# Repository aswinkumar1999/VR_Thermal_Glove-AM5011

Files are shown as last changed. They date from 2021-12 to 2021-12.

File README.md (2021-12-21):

# Virtual reality glove with Thermal Feedback - AM5011

Course Project for AM5011

**Abstract** :  The goal of the is to prototype an affordable VR gloves with thermal interface that provides thermal sensation when the user interacts with the virtual world.

**[Video](https://www.youtube.com/watch?v=WOqCuXHhvuI)** : https://www.youtube.com/watch?v=WOqCuXHhvuI   ( __Subtitles available for Non-Tamil viewers.__)

Unity Package for Oculus Quest 2 : https://drive.google.com/file/d/1xBs8NeNjcjLqpN7lWxxVzRwR7QExw7Z_/view?usp=sharing

Kindly note , this APK will only work on Quest and Quest 2 and requires Hand tracking access! This Unity package is incomplete, meaning you can use whichever method of communication you prefer with the hardware you make. 

The application was run on [Oculus Quest 2](https://www.oculus.com/)

Final prototype : 

<p float="left">
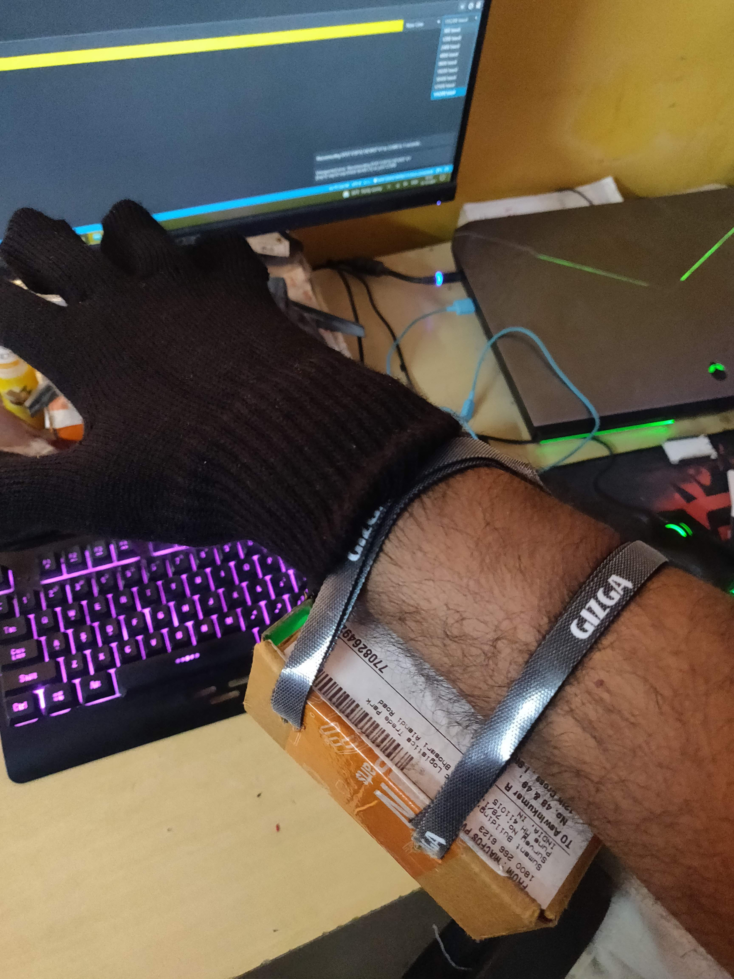
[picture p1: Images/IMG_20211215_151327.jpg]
  
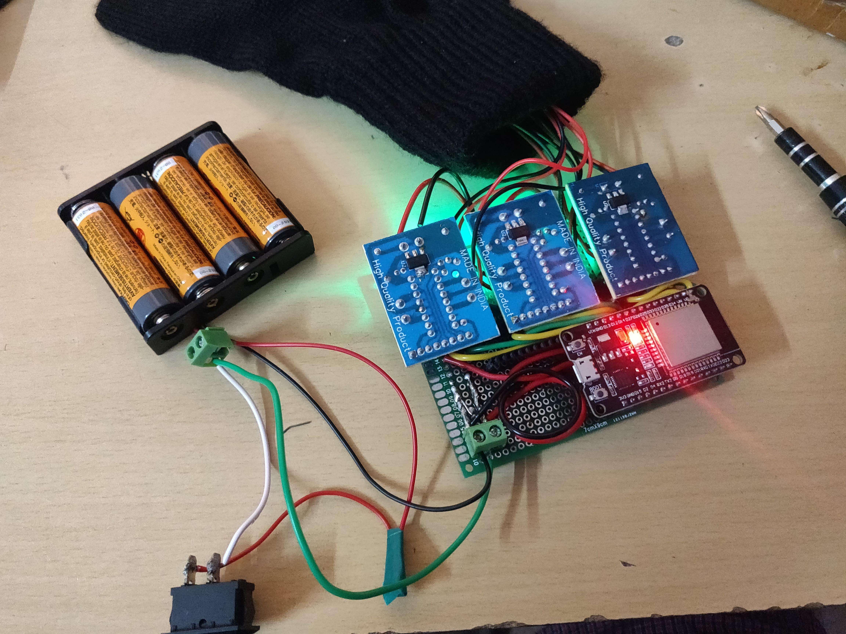
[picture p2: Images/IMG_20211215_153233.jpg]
   
</p>

Schematic : Fritzing file included for designing PCBs for the same.

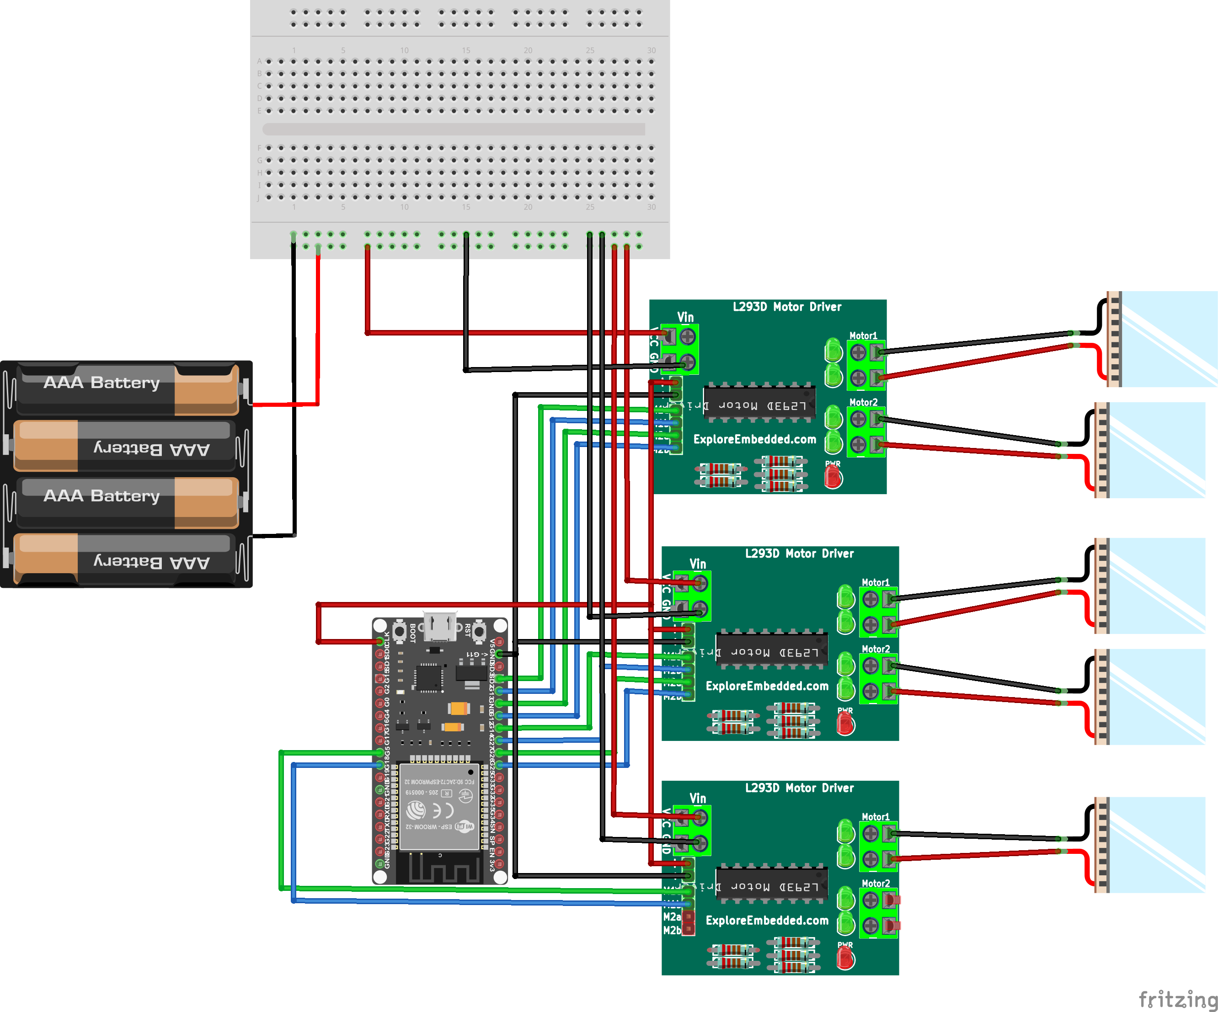
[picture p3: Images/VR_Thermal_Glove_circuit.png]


Code : [ESP32_Glove.ino](https://github.com/aswinkumar1999/VR_Thermal_Glove-AM5011/blob/main/ESP_32_Glove.ino)

----

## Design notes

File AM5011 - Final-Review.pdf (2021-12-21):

# AM5011 - Course Project

# VR Gloves with Thermal Interface

Aswinkumar - EP18B014

# Abstract

- The goal of the is to prototype an affordable VR gloves with thermal interface that provides thermal sensation when the user interacts with the virtual world.

# System block diagram

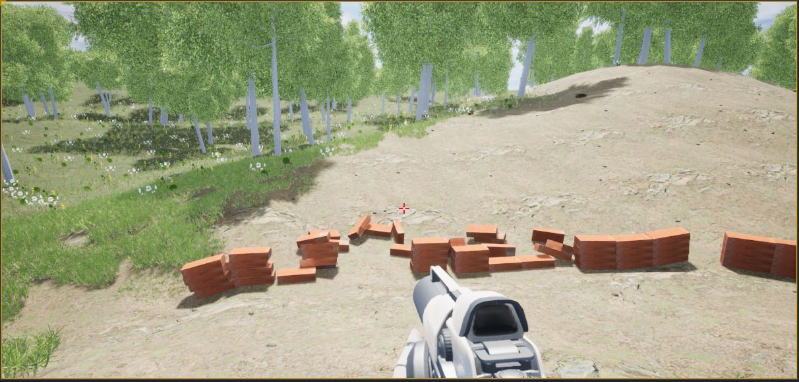
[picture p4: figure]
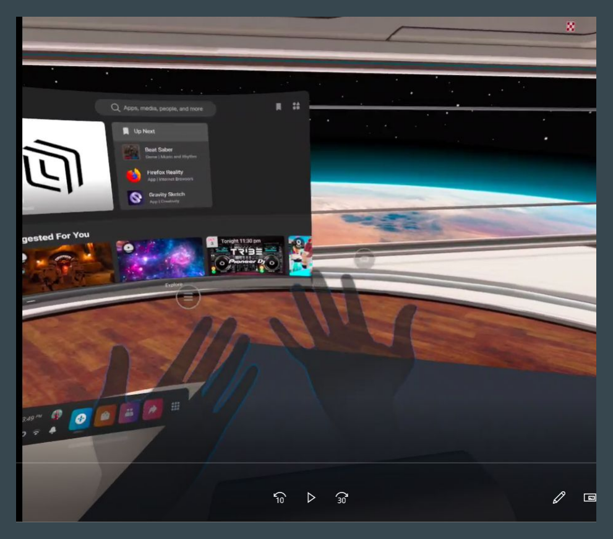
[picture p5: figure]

Need to finalise | Tested & works

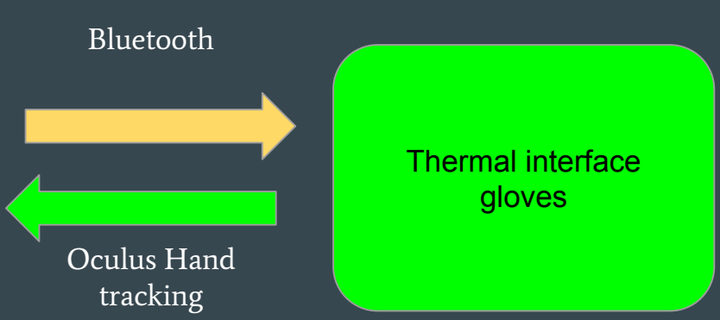
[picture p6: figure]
Thermal interface gloves; Oculus Hand tracking; Bluetooth

Unity

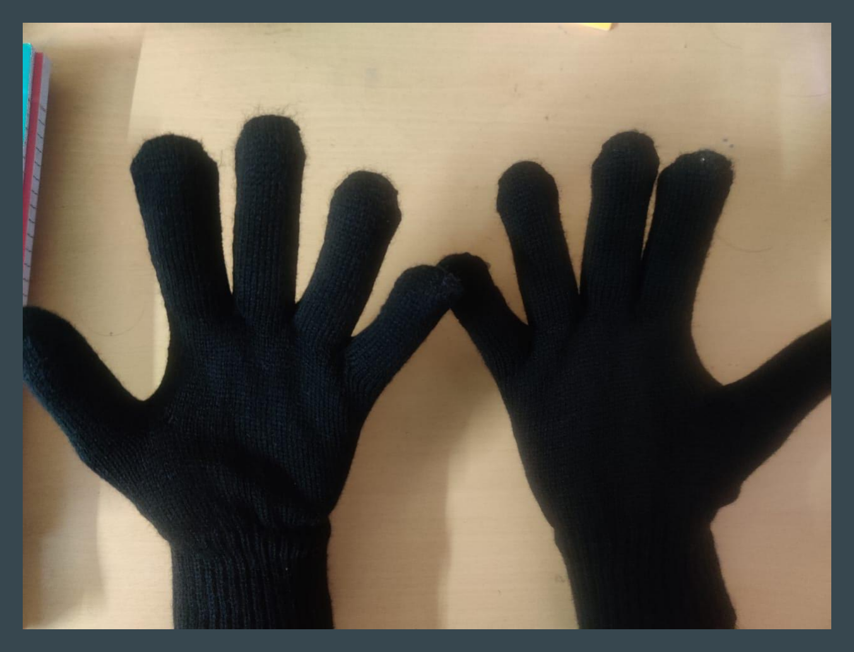
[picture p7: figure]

# Hardware setup

Bluetooth

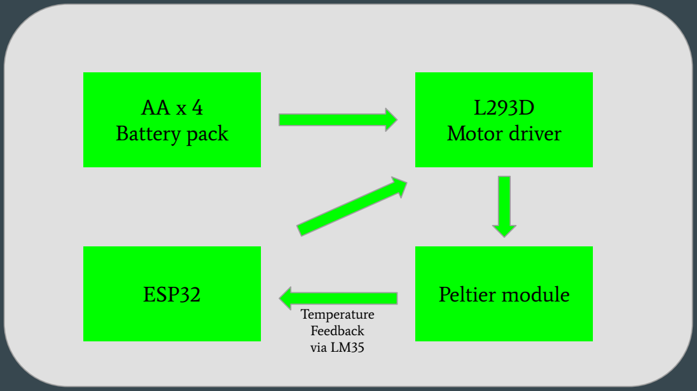
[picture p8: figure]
ESP32; Peltier module; L293D Motor driver; AA x 4 Battery pack; Temperature Feedback via LM35
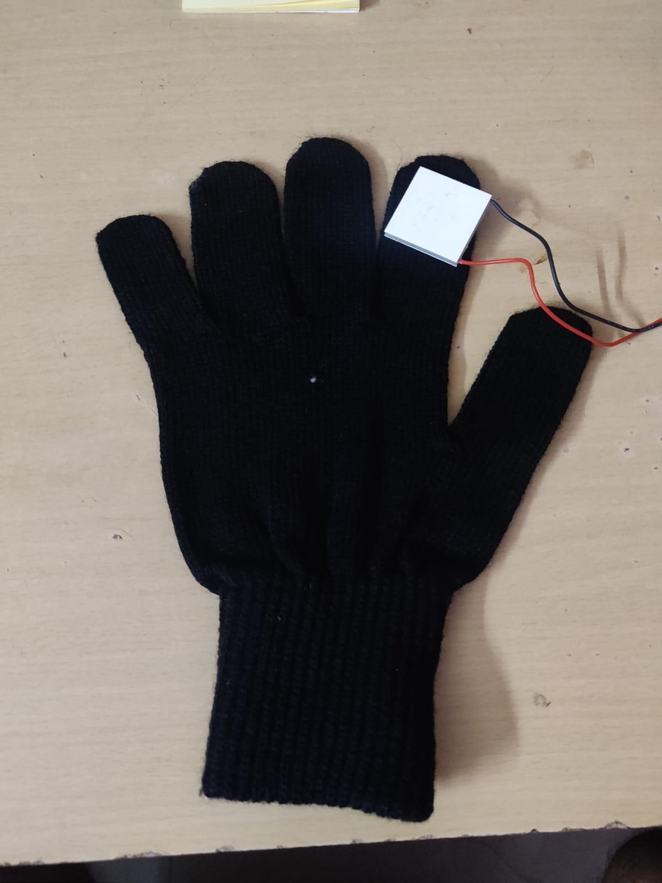
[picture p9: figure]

Need to finalise | Tested & works

# Results :

- Hardware for the project is complete , it is portable and works wirelessly with the battery pack.
- It is currently controlled using a Bluetooth application from an Android device.

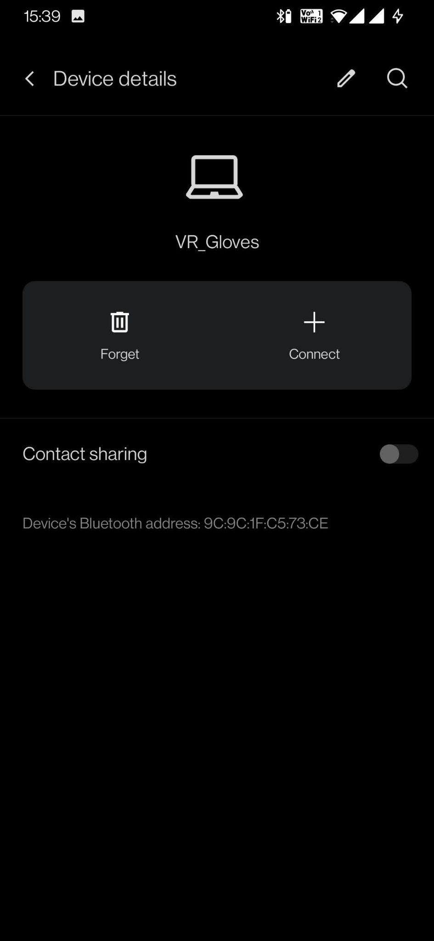
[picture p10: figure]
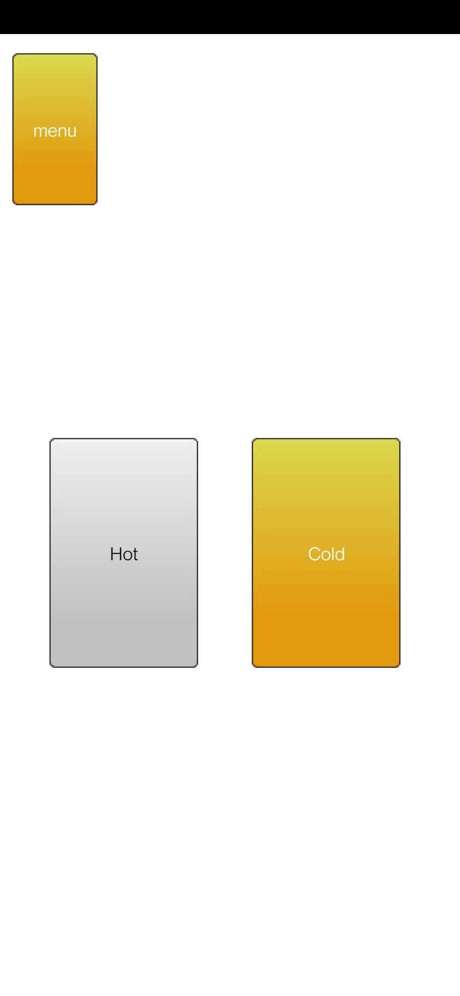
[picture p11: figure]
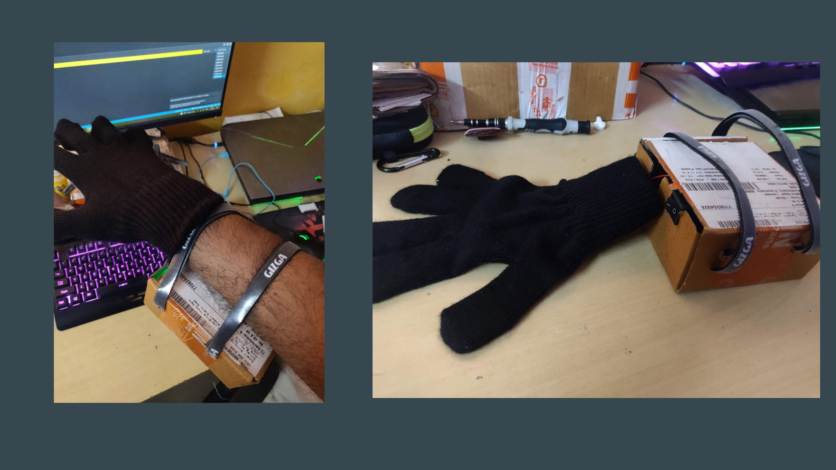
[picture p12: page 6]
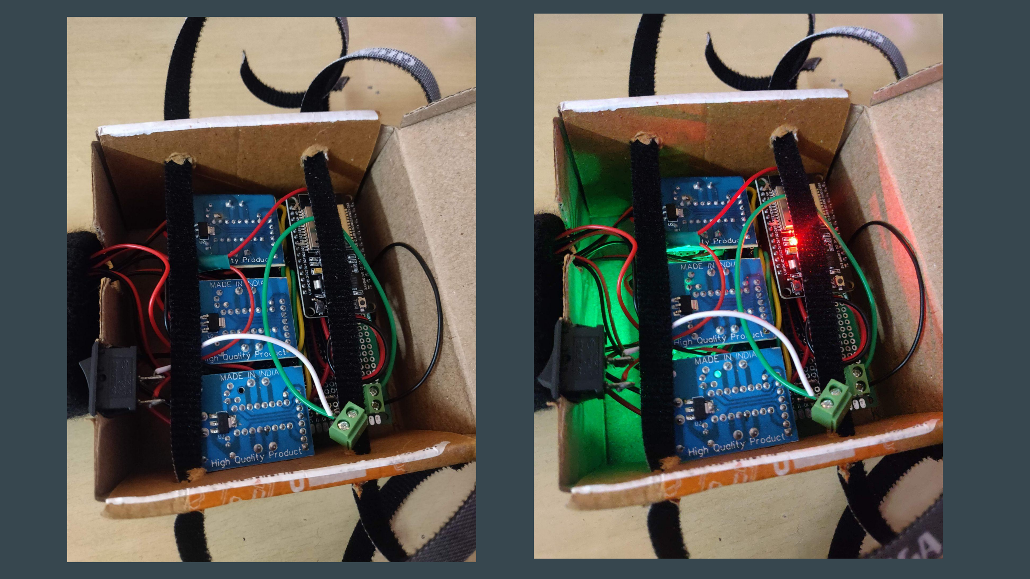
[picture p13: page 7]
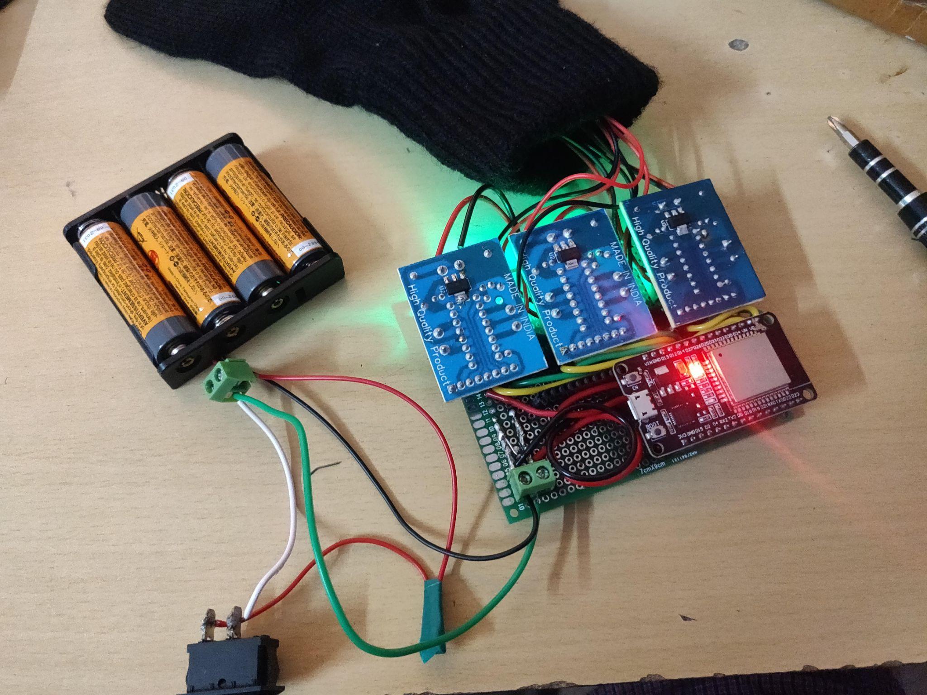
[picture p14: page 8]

# Issues faced while implementation :

- 6V battery packs in parallel crashes the SoC and a single pack has lower slope in change of temperature , need to switch to LiPo battery (7.4V)
- Oculus SDK Plugin Bluetooth issue , Bluetooth isn’t included in the Android manifest and is getting removed automatically.

# Plans for future :

- Changing battery pack to LiPo pack.
- Fixing the Unity bluetooth issue with Oculus plugin.
- Design and fabricate a PCB to have reduced footprint.
- Use a small 3d printed box to fit all the components.

# Something that I found very fascinating during the testing :

- I was pressing buttons for Hot/Cold testing and during the hot mode I involuntarily moved my hand towards my face and neck to transfer the hotness of my hand to my face only to realise that i had the system on ,

# Thank you

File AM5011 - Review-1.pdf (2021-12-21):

# AM5011 - Course Project

# VR Gloves with Interface

Review 1
Aswinkumar - EP18B014

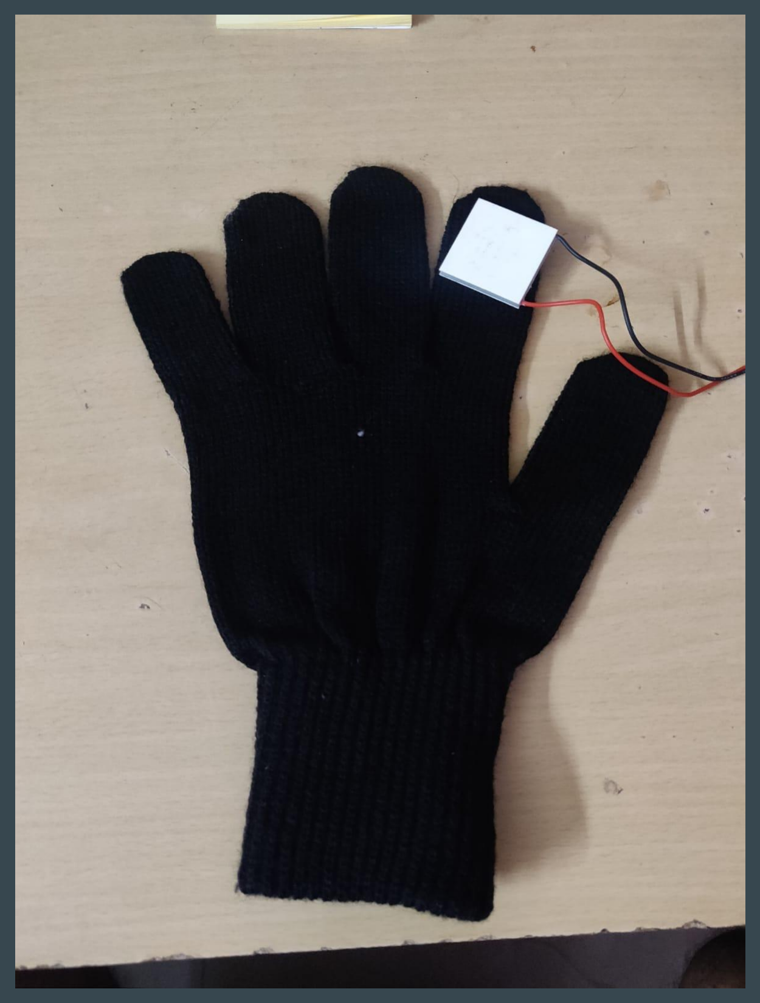
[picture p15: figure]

# VR Gloves with Thermal Interface

- The goal is the make an affordable VR gloves with thermal interface that provides thermal sensation when the user interacts with the virtual world.
- I will be only focusing on providing the sensation to the finger pad as they are one of the most sensitive part of our body.
- Ruffini cells and Nerve endings detect warmth
- Krause end bulb detect cold

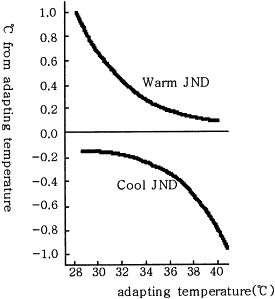
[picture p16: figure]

[1] Development of a temperature control procedure for a room air-conditioner using the concept of just noticeable difference (JND) in thermal sensation
[2] Thermal display glove for interacting with virtual reality

# System block diagram


Need to finalise | Tested & works

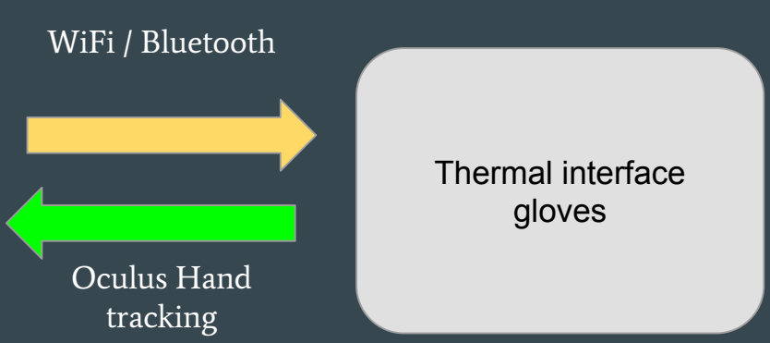
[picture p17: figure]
Thermal interface gloves; Oculus Hand tracking; WiFi / Bluetooth

Unity / Unreal


# Oculus hand-tracking :

The OVR Skeleton and OVR Hand APIs provide information required to render a fully articulated representation of the user’s real-life hands in VR without the use of controllers, including:

- Bone information
- Hand and finger position and orientation
- Pinch strength
- Pointer pose for UI raycasts
- Tracking confidence
- Hand size
- System gesture for opening the universal menu

# Hardware setup

WiFi / Bluetooth

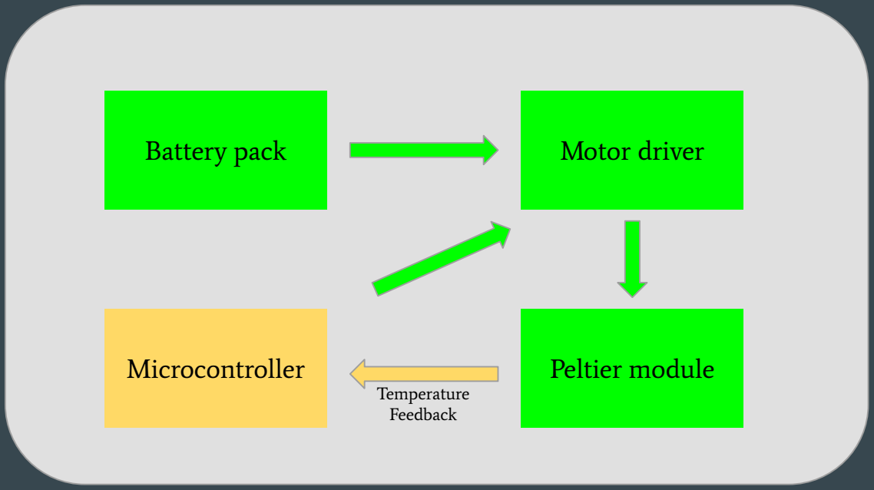
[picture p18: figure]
Microcontroller; Peltier module; Battery pack; Motor driver; Temperature Feedback

Need to finalise | Tested & works

# Test / Prototype setup

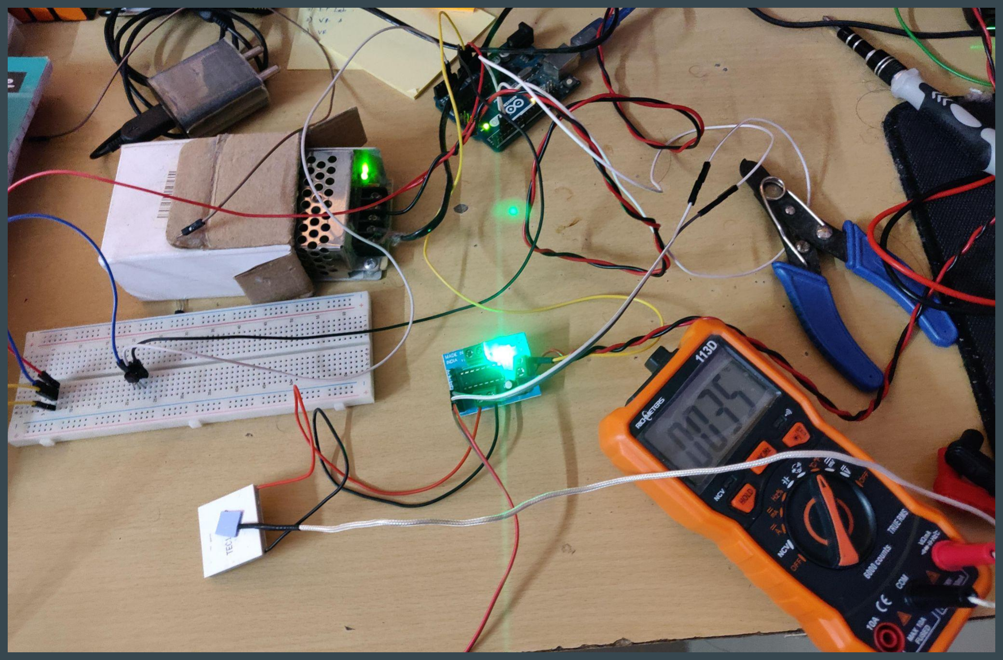
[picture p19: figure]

# Calculating temperature gradient ( dT/dt )

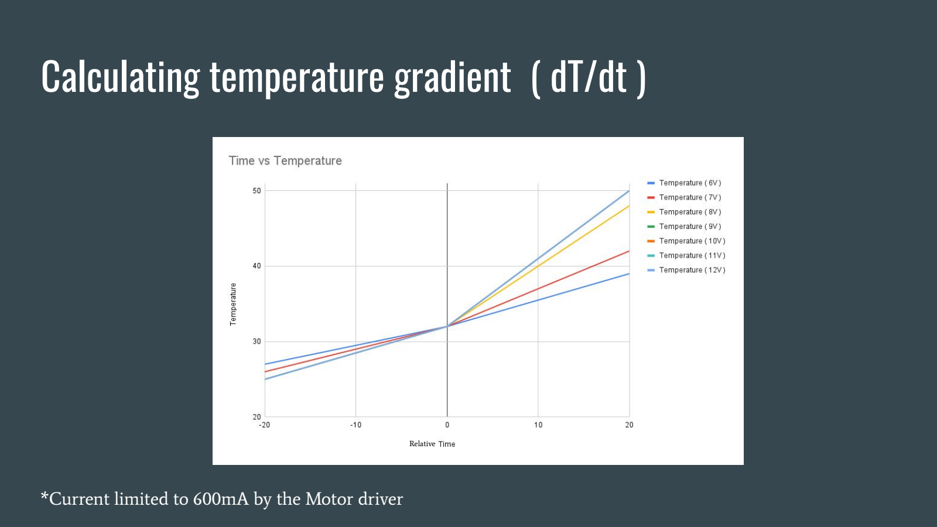
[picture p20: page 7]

*Current limited to 600mA by the Motor driver

Relative

# Plotting more points and curve fitting

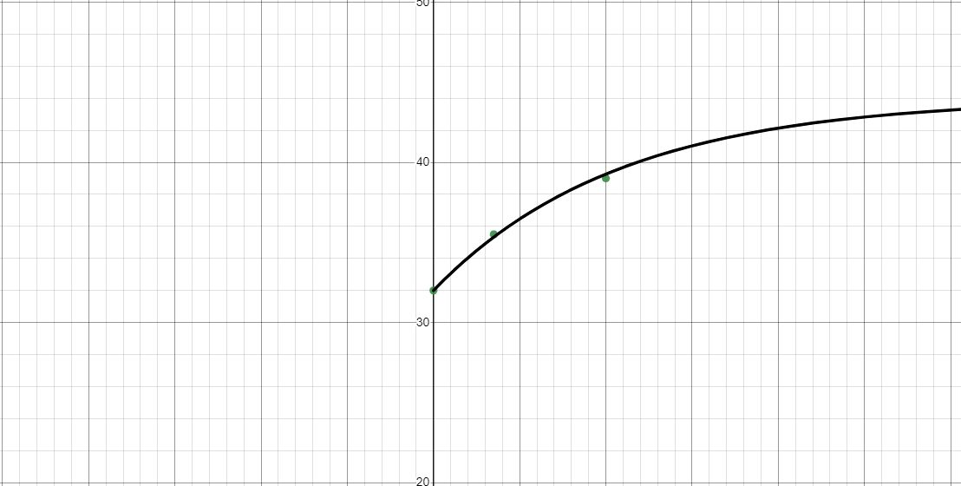
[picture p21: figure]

*Current limited to 600mA by the Motor driver

# Results & Observations :

- The temperature changes require time to fully take effect thereby eliminating applications which need instantaneous results. ( Ex : Touching a hot pan )
- However the majority of change in temperature still happens within a few seconds ( 2-5 secs ) , this can be utilized for applications where we bring our hands near a slightly warmer or colder object
(Ex : Soda can / Vapour from boiling water )
- Hot applications can benefit better in this case and I plan to focus on them particularly.
- Power law exponent of Temperature ( Cold ) = 1.0
- Power law exponent of Temperature ( Warmth ) = 1.6

# Plans for further reviews :

Review 2 :
- Complete glove hardware and program it.
- Finalise Game-engine and Microcontroller
Review 3 :
- Build a basic interface between Hardware and software and tweak the hardware to better suit the application.
Final submission :
- Have a complete environment that allows thermal feedback to the gloves.

# Estimated cost :

Hardware :

- Peltier : 290 x 5 = 1450
- Microcontroller = ~500
- Motor driver = ~400
- Temperature sensor = ~400
- Misc = ~250

Software :
- Plugin for Interface = 20$ = ~1500

Total : 3000 + 1500 = ~4500

# Thank you

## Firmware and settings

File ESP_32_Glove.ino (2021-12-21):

#include "BluetoothSerial.h" //Header File for Serial Bluetooth, will be added by default into Arduino

BluetoothSerial ESP_BT; //Object for Bluetooth

int incoming;

// Peltier 1 
int M1P1 = 12; 
int M1P2 = 13;
// Peltier 2
int M2P1 = 27; 
int M2P2 = 14; 
// Peltier 3 
int M3P1 = 26; 
int M3P2 = 25;
// Peltier  4
int M4P1 = 33; 
int M4P2 = 32;
// Peltier 5 
int M5P1 = 19; 
int M5P2 = 21;


void setup() {
  // sets the pins as outputs:
    // P1 
    pinMode(M1P1, OUTPUT);
    pinMode(M1P2, OUTPUT);
    // P2 
    pinMode(M2P1, OUTPUT);
    pinMode(M2P2, OUTPUT);
    // P3 
    pinMode(M3P1, OUTPUT);
    pinMode(M3P2, OUTPUT);
    // P4 
    pinMode(M4P1, OUTPUT);
    pinMode(M4P2, OUTPUT);
    // P5 
    pinMode(M5P1, OUTPUT);
    pinMode(M5P2, OUTPUT);
  

  Serial.begin(115200);
  ESP_BT.begin("VR_Gloves"); //Name of your Bluetooth Signal
  Serial.println("Bluetooth Device is Ready to Pair");
}

void loop() {

  if (ESP_BT.available()) //Check if we receive anything from Bluetooth
  {
    incoming = ESP_BT.read(); //Read what we recevive 
    Serial.print("Received:"); Serial.println(incoming);

    if (incoming == 49) // 1 - Hot
        {
        digitalWrite(M1P1, LOW);
        digitalWrite(M1P2, HIGH); 
        digitalWrite(M2P1, LOW);
        digitalWrite(M2P2, HIGH); 
        digitalWrite(M3P1, LOW);
        digitalWrite(M3P2, HIGH); 
        digitalWrite(M4P1, LOW);
        digitalWrite(M4P2, HIGH); 
        digitalWrite(M5P1, LOW);
        digitalWrite(M5P2, HIGH); 
        }
        
    if (incoming == 48) // 0 - Stop 
        {
        digitalWrite(M1P1, LOW);
        digitalWrite(M1P2, LOW); 
        digitalWrite(M2P1, LOW);
        digitalWrite(M2P2, LOW); 
        digitalWrite(M3P1, LOW);
        digitalWrite(M3P2, LOW); 
        digitalWrite(M4P1, LOW);
        digitalWrite(M4P2, LOW); 
        digitalWrite(M5P1, LOW);
        digitalWrite(M5P2, LOW); 
        } 
    if (incoming == 50) // 2 - Cold 
        {
        digitalWrite(M1P2, LOW);
        digitalWrite(M1P1, HIGH); 
        digitalWrite(M2P2, LOW);
        digitalWrite(M2P1, HIGH); 
        digitalWrite(M3P2, LOW);
        digitalWrite(M3P1, HIGH); 
        digitalWrite(M4P2, LOW);
        digitalWrite(M4P1, HIGH); 
        digitalWrite(M5P2, LOW);
        digitalWrite(M5P1, HIGH); 
        } 
  }
  delay(20);
}
